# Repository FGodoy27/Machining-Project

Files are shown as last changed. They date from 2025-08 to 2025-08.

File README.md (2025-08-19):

## Ballerina Project
### Ballerina Project Description
This is a project for the machining course, where we were given the option of making a figure with a free design and measurements, taking into account only the availability of materials in the laboratory.
For this project, we needed to use all the machines we have in the laboratory (milling machine, lathe, drill, planer).
It was necessary to calculate all the cuts and processes required, calculations that will be attached to this repository.

### Ballerina Project Final Assembly
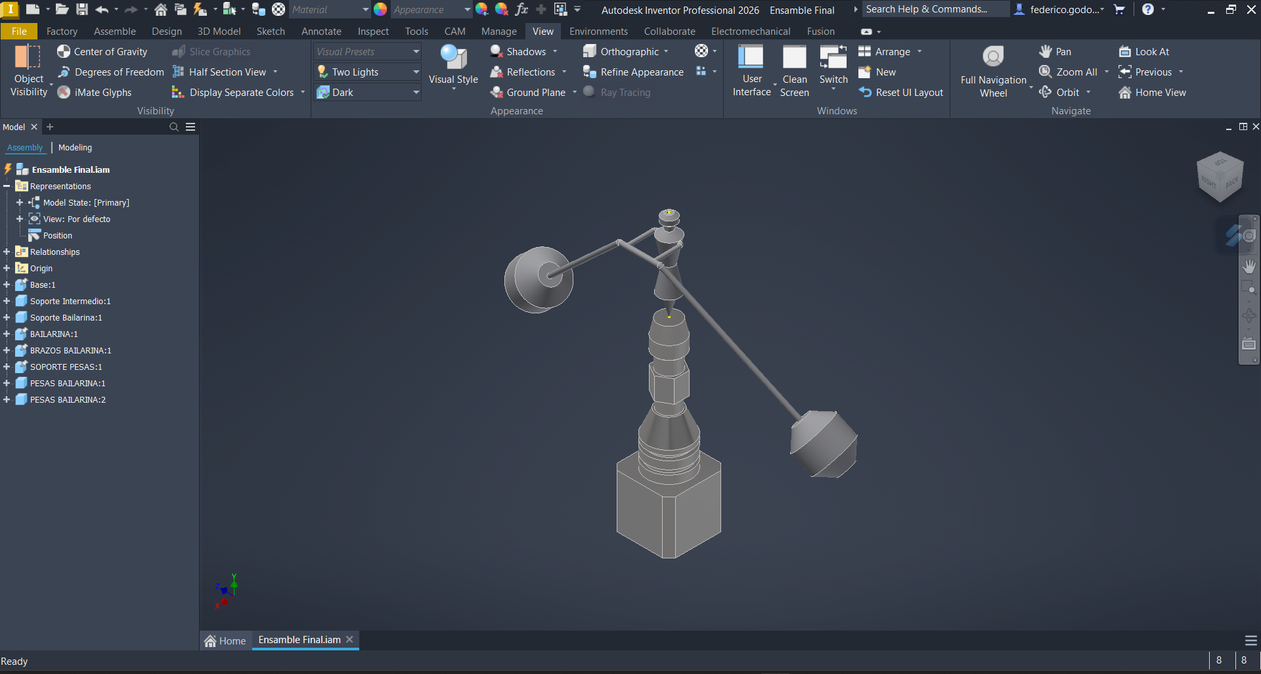
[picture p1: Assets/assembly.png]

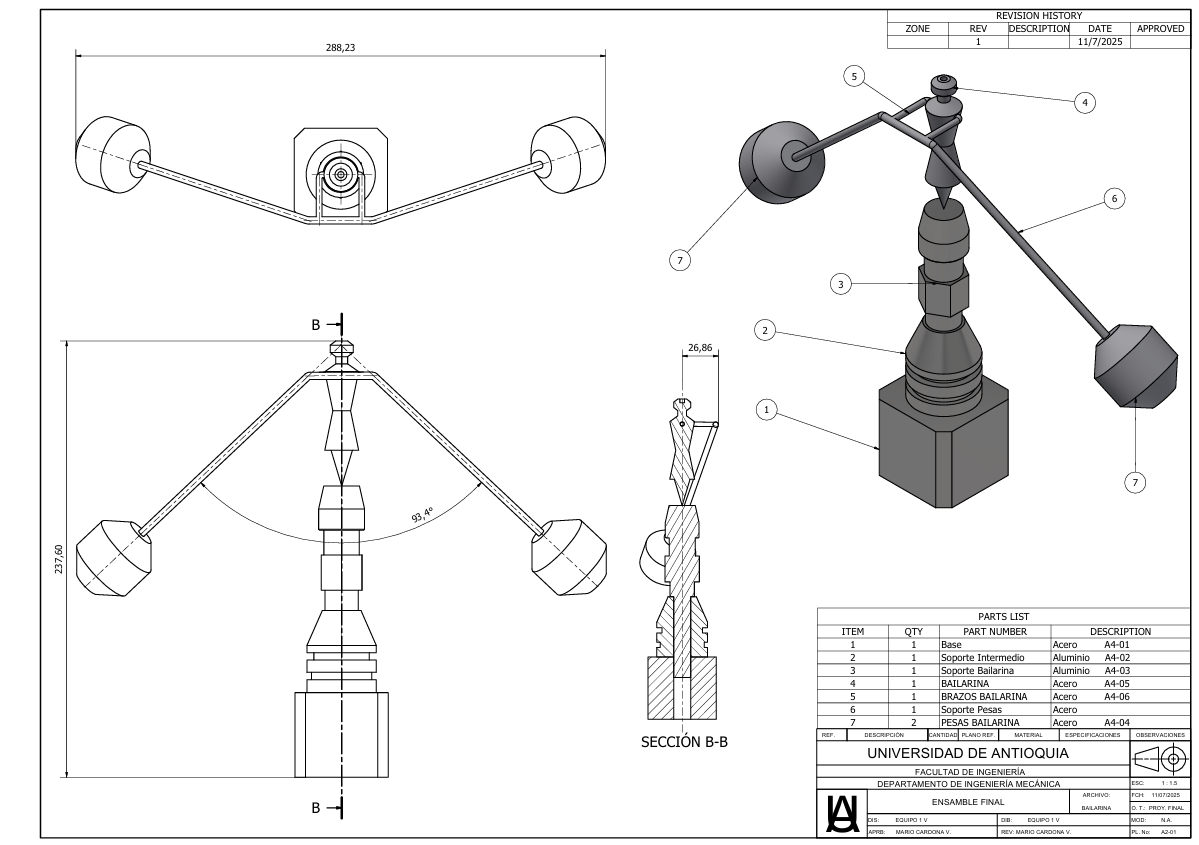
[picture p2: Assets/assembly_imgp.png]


### Final Result of the Ballerina Project
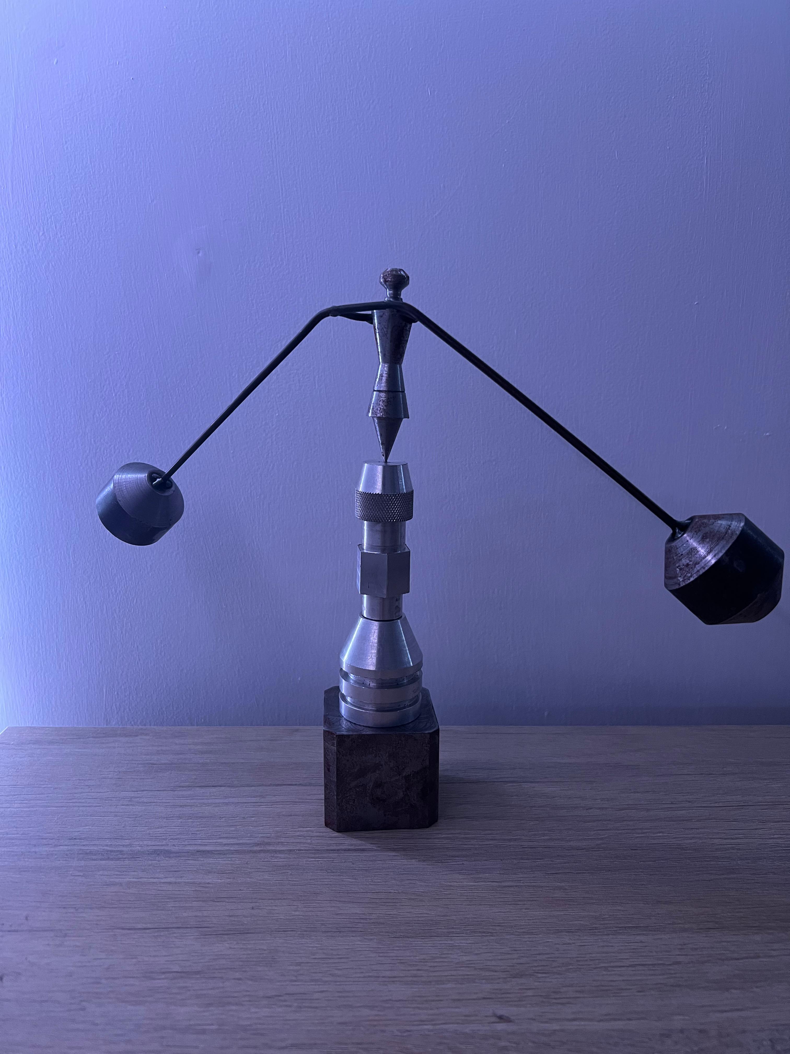
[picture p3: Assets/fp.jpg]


### Ballerina Base
The base was made of 1020 steel.
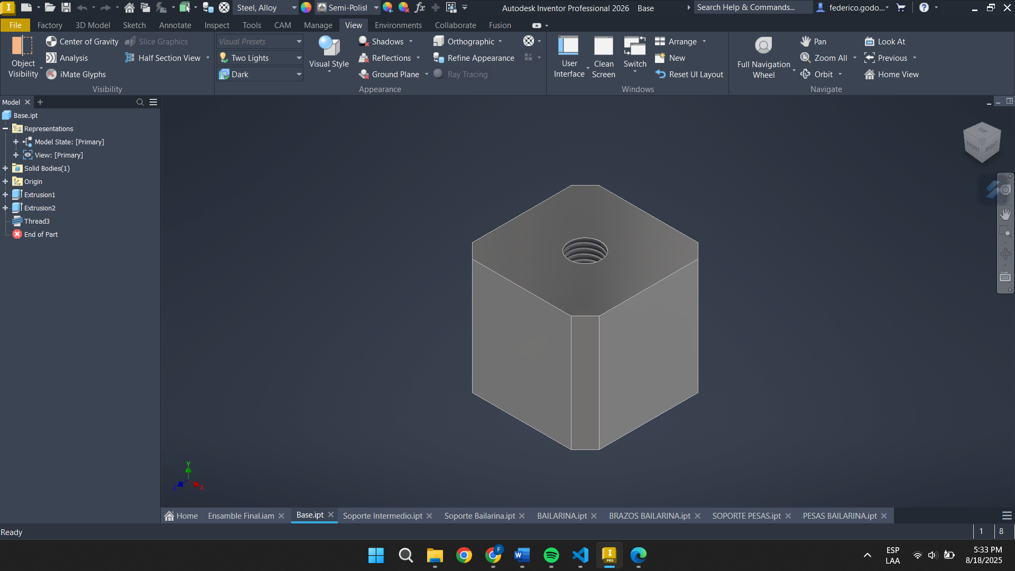
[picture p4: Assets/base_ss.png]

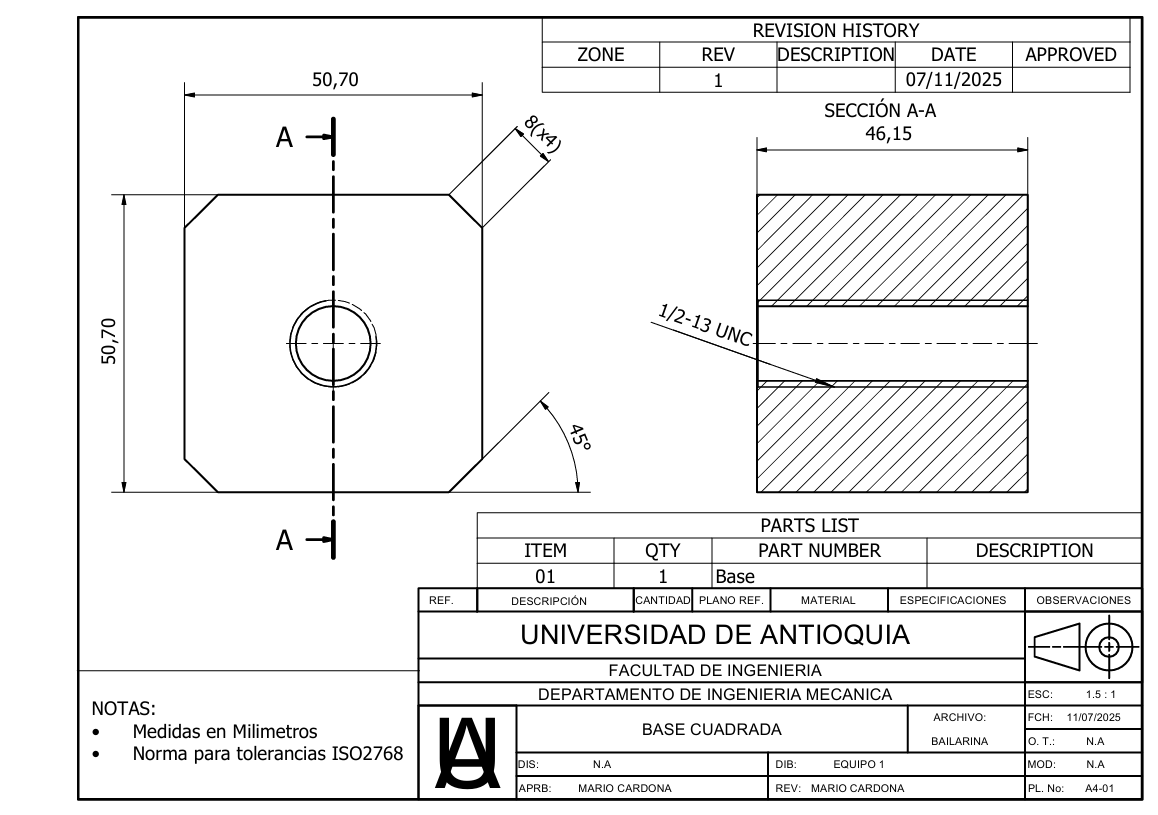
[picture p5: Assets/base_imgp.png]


### Ballerina Intermediate Support
The intermediate support is made of aluminum.
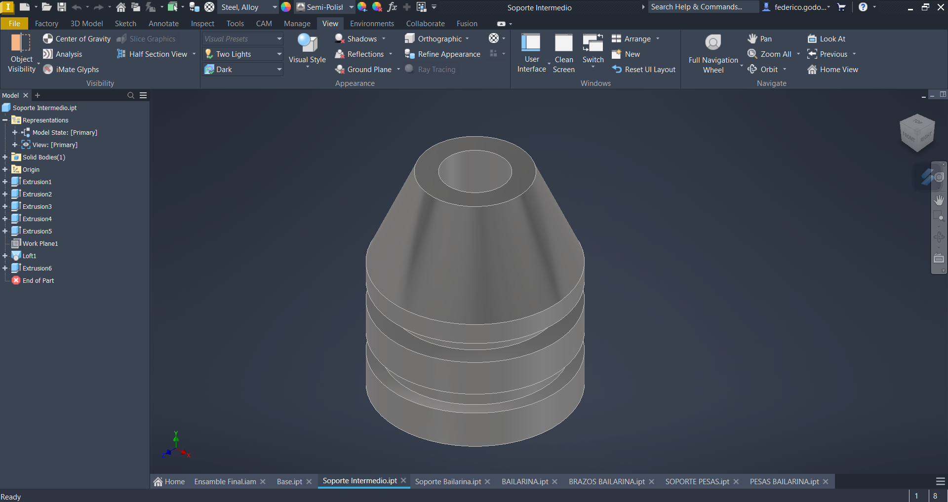
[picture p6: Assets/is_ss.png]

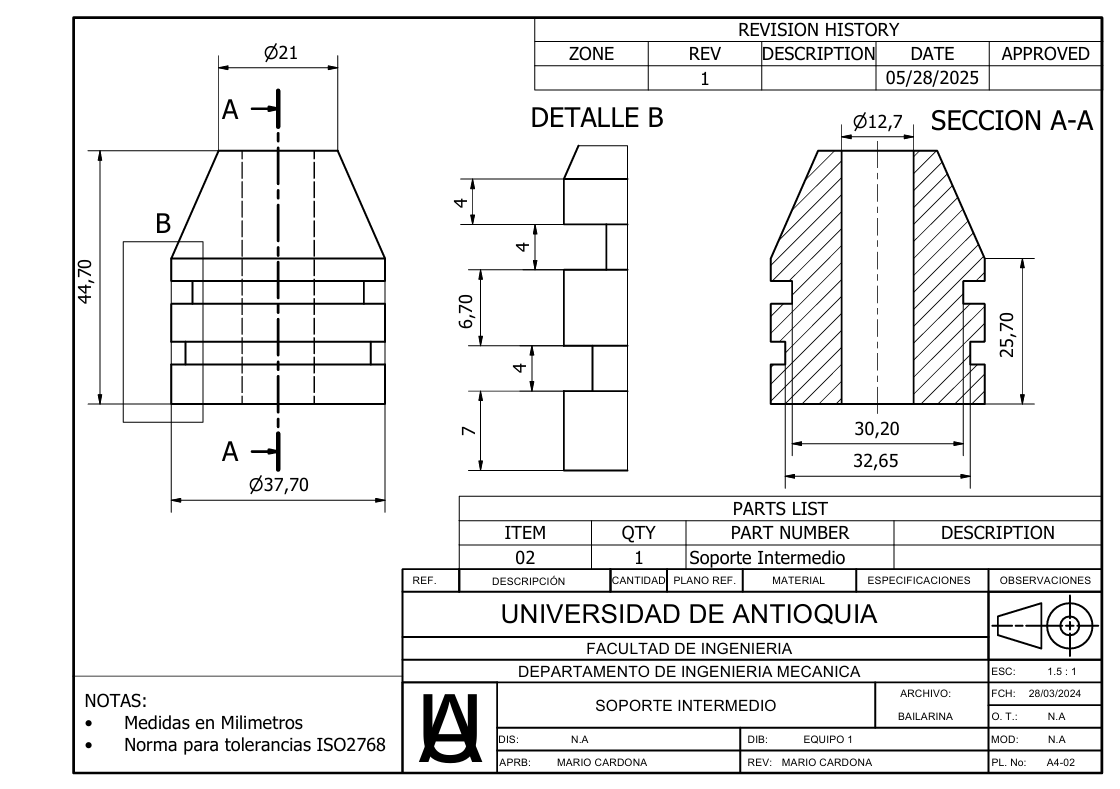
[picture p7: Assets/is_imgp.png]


### Ballerina Main Support 
The main support is made of aluminum.
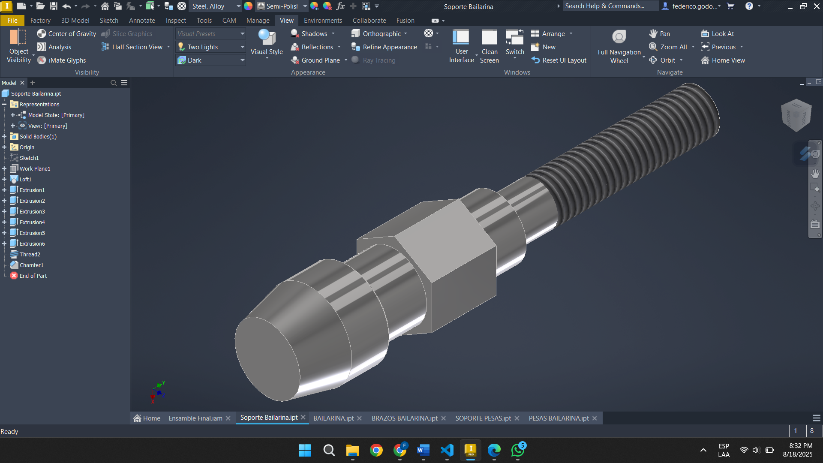
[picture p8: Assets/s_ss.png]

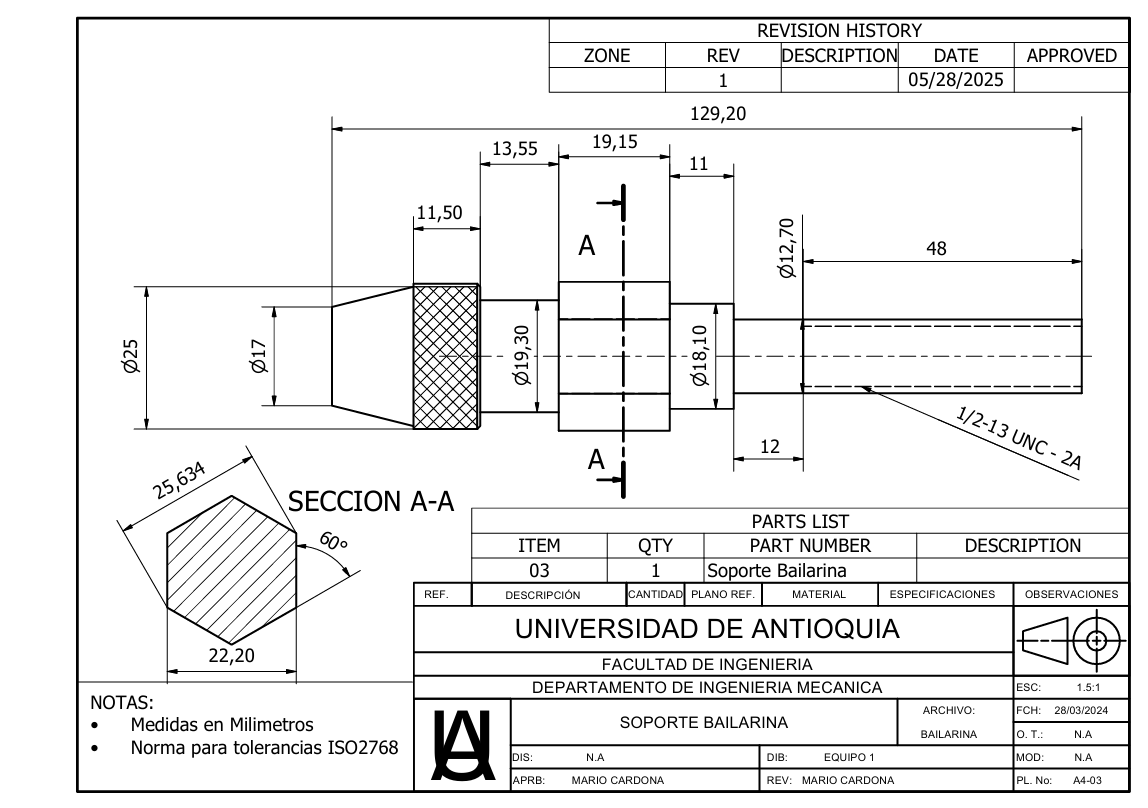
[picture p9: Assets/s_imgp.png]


### Ballerina
The ballerina was made of 1020 steel.
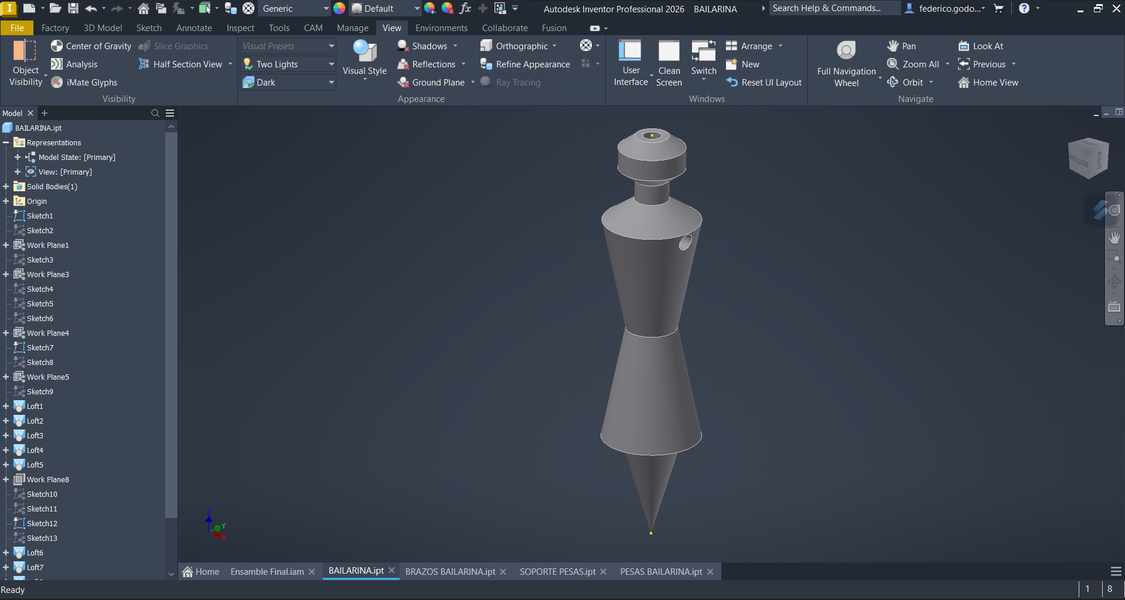
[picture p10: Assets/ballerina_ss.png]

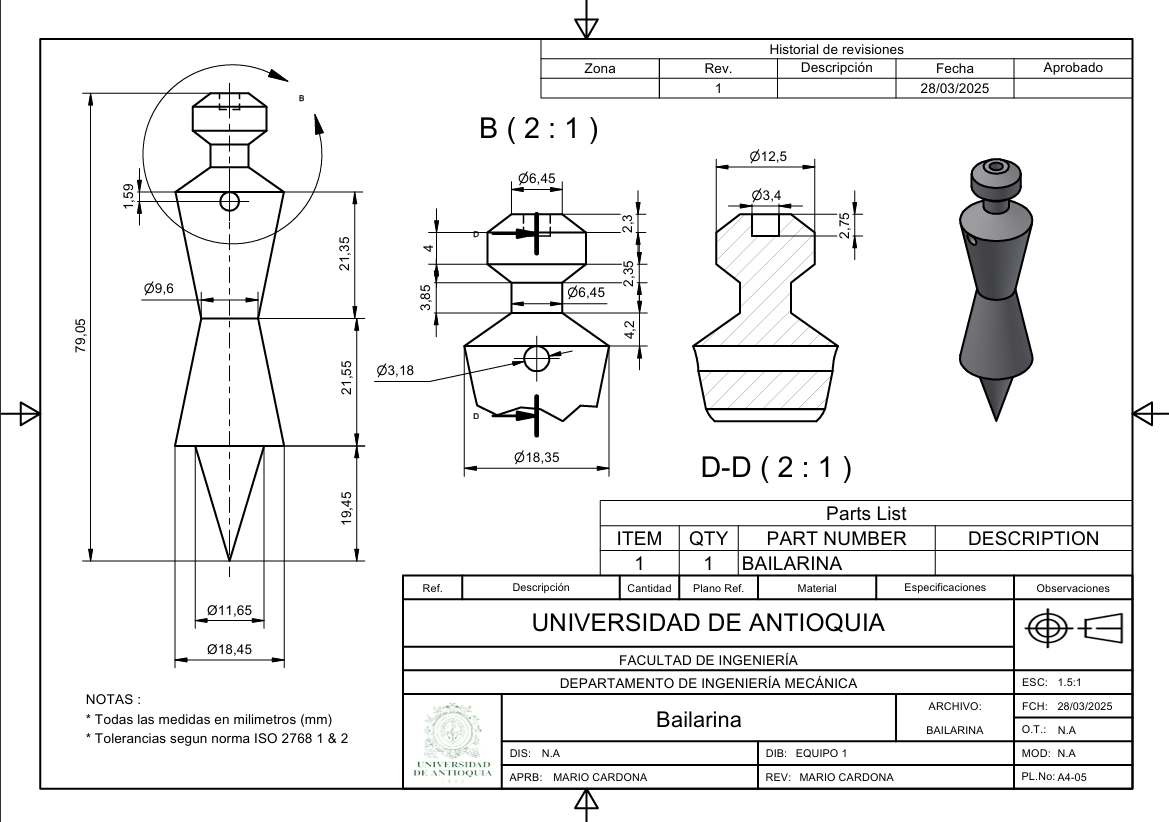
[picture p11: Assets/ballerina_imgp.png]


### Ballerina Arms
The ballerina arms were made of 1020 steel.
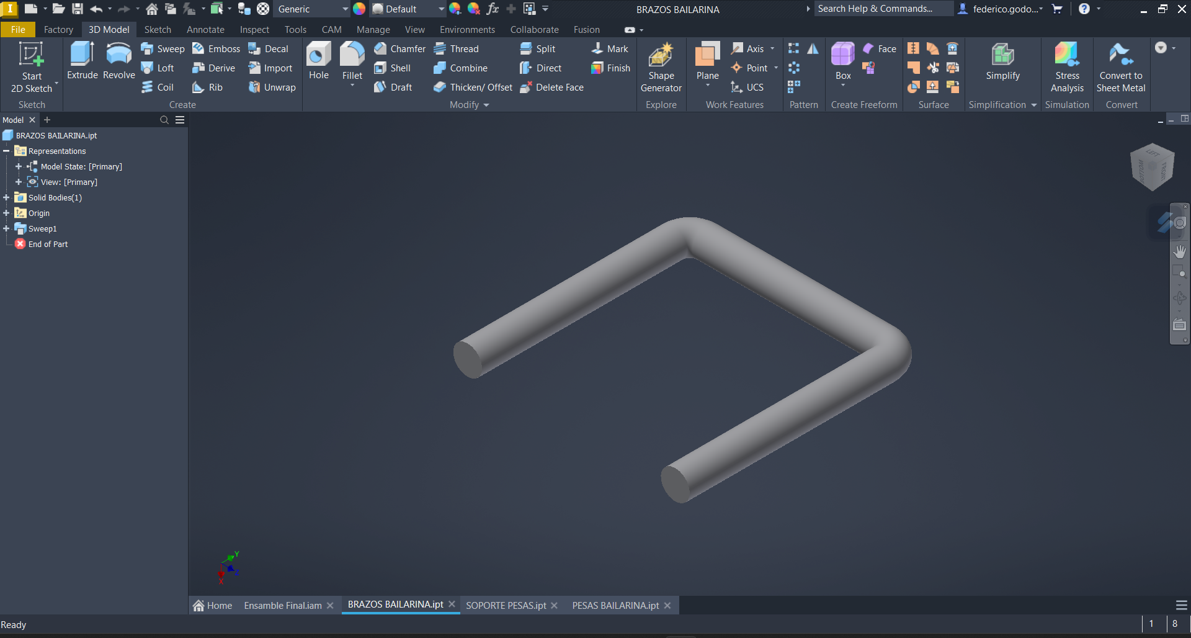
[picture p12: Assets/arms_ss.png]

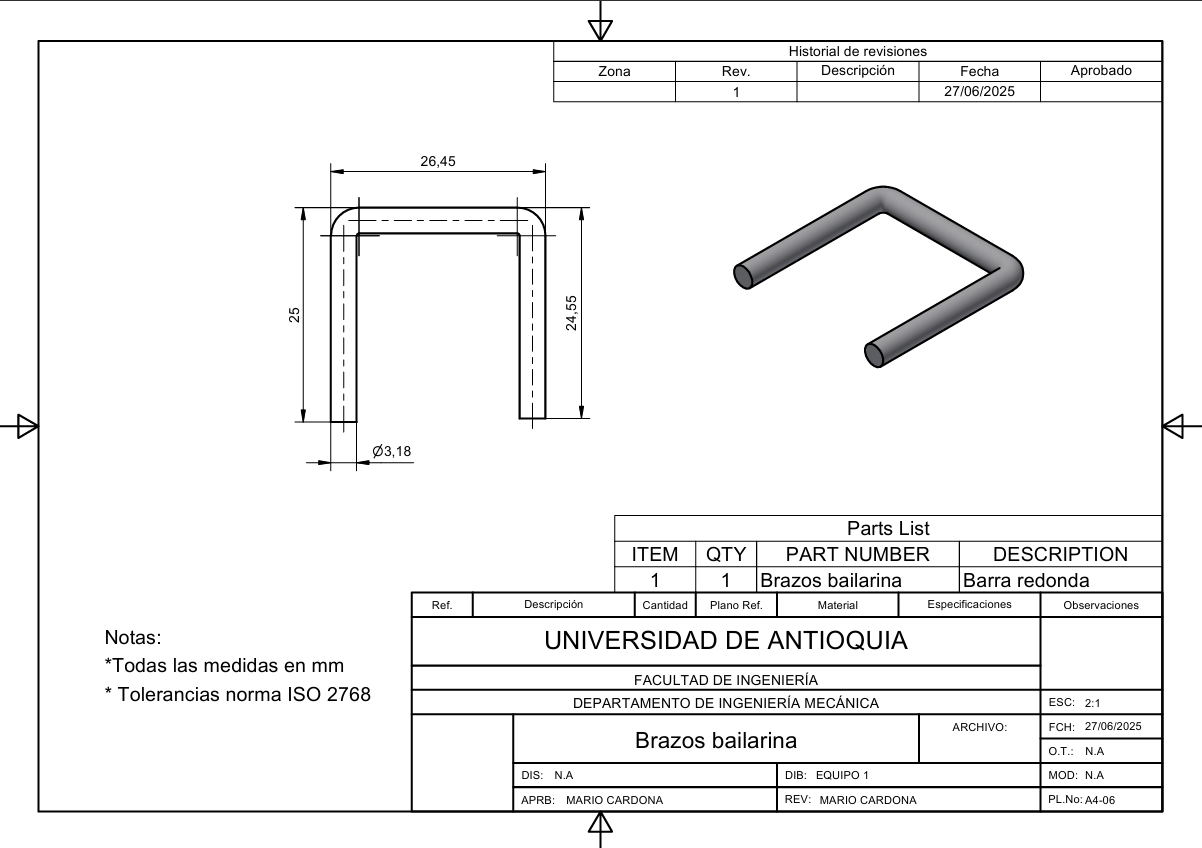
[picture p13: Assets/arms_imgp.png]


### Weight Support
The weight support of the ballerina was made of 1020 steel
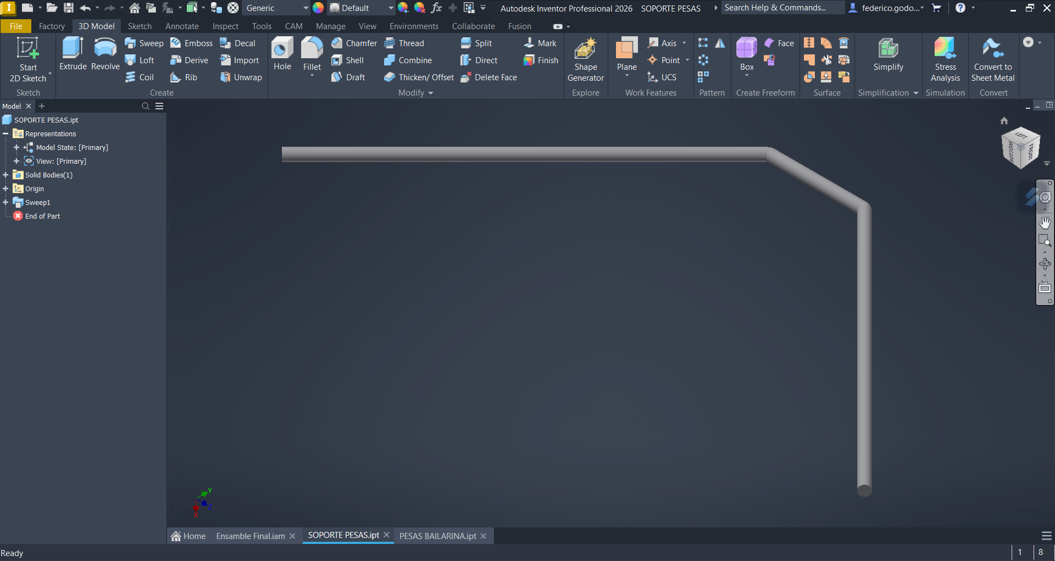
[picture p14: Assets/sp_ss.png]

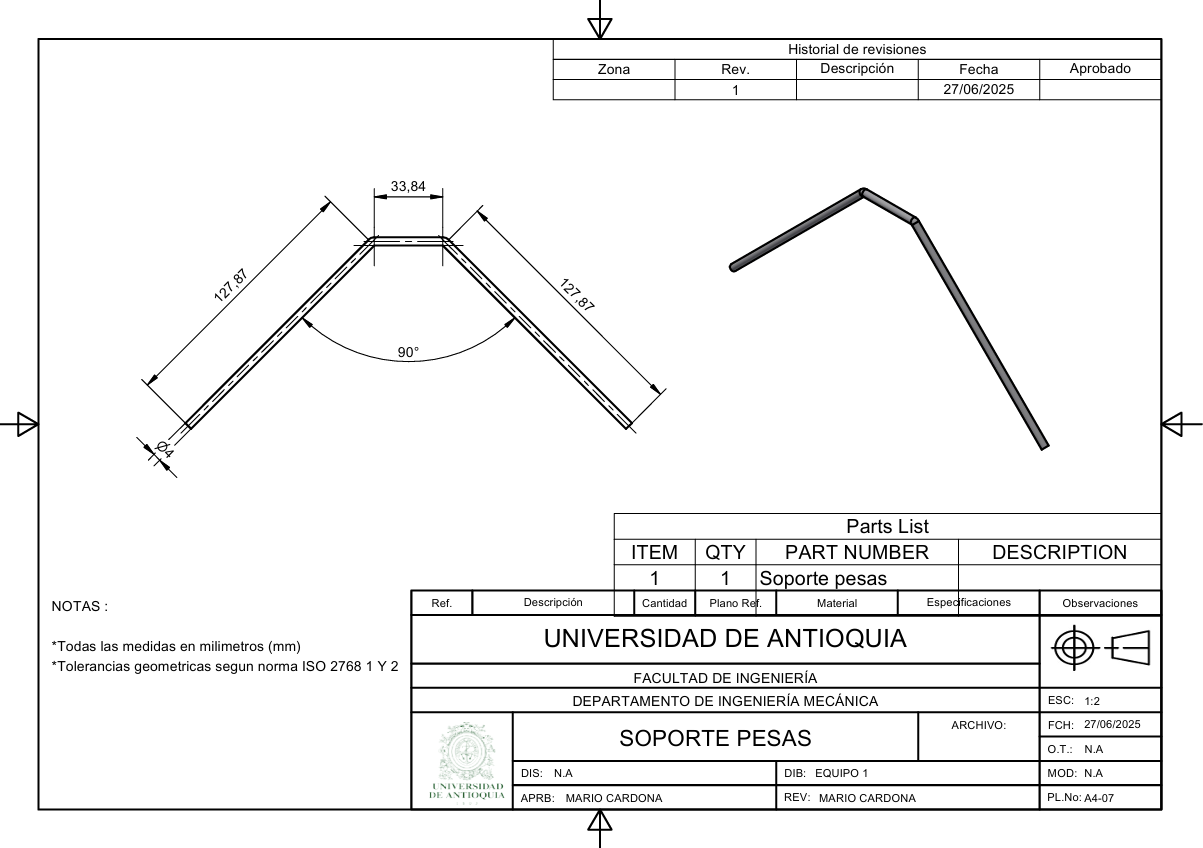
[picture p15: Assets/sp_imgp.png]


### Weights
The weights were made of 1020 steel
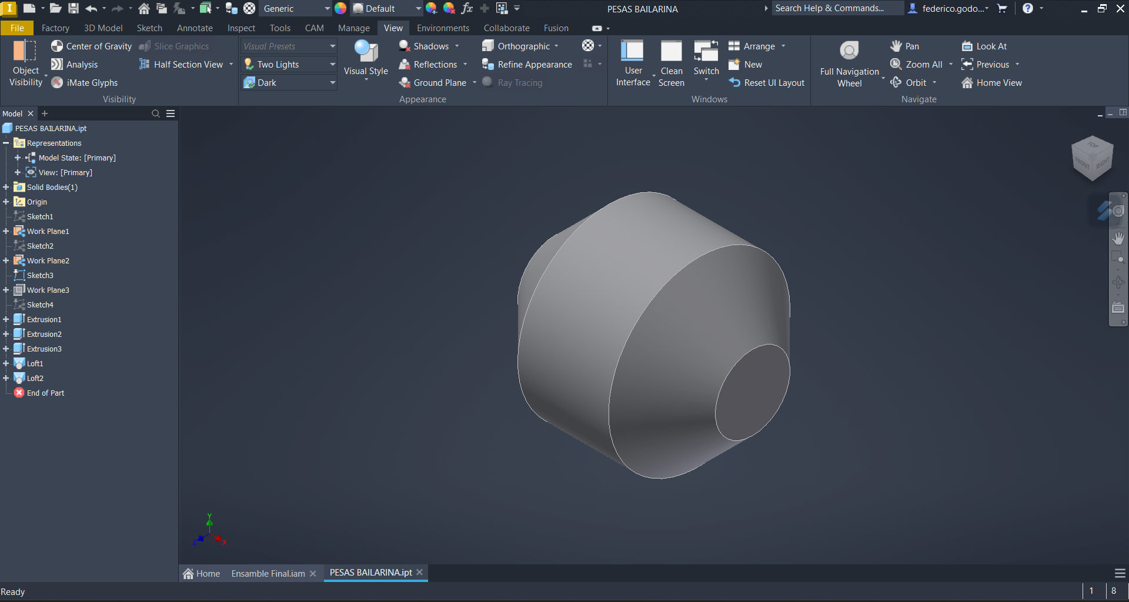
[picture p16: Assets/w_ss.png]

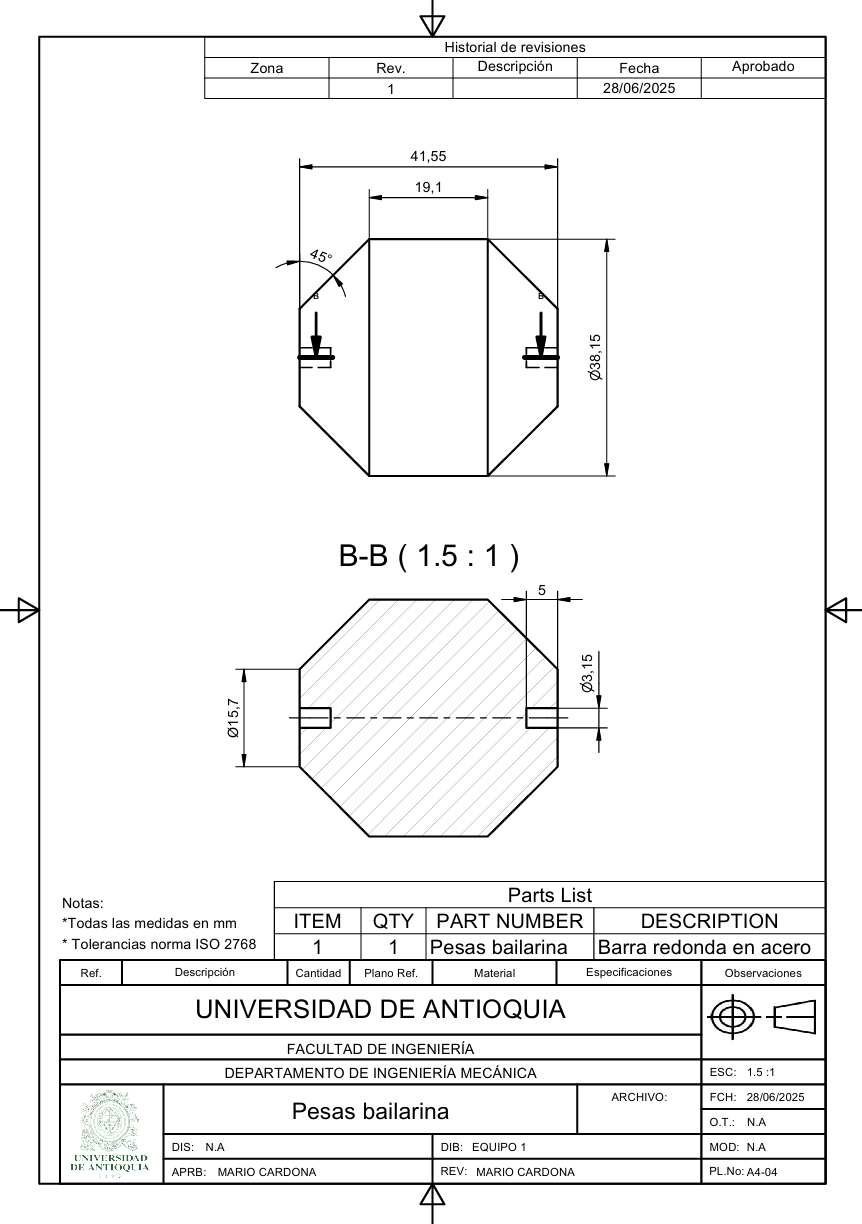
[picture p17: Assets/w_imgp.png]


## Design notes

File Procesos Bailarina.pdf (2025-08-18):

Pieza: BASE

Material: ACERO AISI 1020
Cantidad: 1
Plano: A4-01
N° | DESCRIPCIÓN | MÁQUINA | HERRAMIENTA | Vc [m/min] | RPM | f [in/rev] | Ap [mm] | # Cortes | Montaje | T. Máquina | T. Montaje
1 | Levantamiento de piezas. | N/A | Pie de rey, escuadra, galgas, Inventor. | N/A | N/A | N/A | N/A | N/A | N/A | 0:05:00 | N/A
2 | Corte de barra 50.8x50.8 mm, longitud 54.77 mm. | Sierra mecánica sin fin | Lima, pie de rey, tiza, rayador | 3.2 | 20 | N/A | N/A | 1 | Montaje al aire | 0:00:45 | 0:02:53
3 | Refrentado de ambas caras para alcanzar 50.70 mm. | Limadora | Buril HSS 1/2", refrigerante | 18.3 | — | 0.010 | 2.0 | 2 | Montaje en prensa fija | 0:08:00 | 0:25:00
4 | Corte de aristas 1 a 4. | Fresadora | Fresa de carburo, refrigerante | 60 | 750 | 0.15 | 1.5 | 4 | Montaje en prensa fija | 0:15:00 | 0:20:00
5 | Taladrado Ø10.72 mm, profundidad 42 mm. | Taladro radial | Broca 27/64", refrigerante, prensa | 30 | 900 | N/A | 42 | 1 | Montaje con prensa | 0:03:00 | 0:03:00
6 | Rosca interna 1/2-13 UNC | Manual | Juego de machuelos y bandeador | N/A | N/A | N/A | N/A | 3 | Montaje en prensa | 0:04:00 | 0:05:00
7 | Redondeos en aristas superiores | Esmeril | Gafas, limadora plana | N/A | N/A | N/A | N/A | N/A | Montaje manual | N/A | 0:05:00

Pieza: SOPORTE INTERMEDIO

Material: ALUMINIO
Cantidad: 1
Plano: A4-02
N° | DESCRIPCIÓN | MÁQUINA | HERRAMIENTA | Vc [m/min] | RPM | f [in/rev] | Ap [mm] | # Cortes | Montaje | T. Máquina | T. Montaje
1 | Levantamiento de piezas. | N/A | Pie de rey, escuadra, galgas, Inventor. | N/A | N/A | N/A | N/A | N/A | N/A | 0:05:00 | N/A
2 | Corte de barra Ø44.7 mm, longitud 46.7 mm. | Sierra mecánica sin fin | Lima, pie de rey, tiza, rayador | 3.2 | 20 | N/A | N/A | 1 | Montaje al aire | 0:00:45 | 0:01:20
3 | Refrentado de ambas caras hasta 44.7 mm. | Torno paralelo | Buril HSS 1/4”, refrigerante | 53 | 450 | Manual | 0.8 | 2 | Montaje al aire | 0:04:00 | 0:03:00
4 | Centrado cara 1 | Torno paralelo | Broca centro, portamadriles | 21 | 900 | N/A | N/A | 1 | Montaje al aire | 0:01:00 | 0:01:00
5 | Ranurado Ø21 mm a Ø17 mm, longitud 25 mm | Torno paralelo | Buril ranurado, refrigerante | 27 | 450 | Manual | 0.63 | 3 | Montaje con contrapunto | 0:05:00 | 0:03:30
6 | Taladrado pasante Ø12.7 mm | Taladro de banco | Broca 1/2”, refrigerante | 30 | 3000 | N/A | N/A | 1 | Montaje con prensa | 0:02:00 | 0:02:00

Pieza: SOPORTE BAILARINA

Material: ALUMINIO
Cantidad: 1
Plano: A4-03
N° | DESCRIPCIÓN | MÁQUINA | HERRAMIENTA | Vc [m/min] | RPM | f [in/rev] | Ap [mm] | # Cortes | Montaje | T. Máquina | T. Montaje
1 | Levantamiento de piezas y análisis de geometría. | N/A | Pie de rey, galgas, escuadra, Inventor | N/A | N/A | N/A | N/A | N/A | N/A | 0:05:00 | N/A
2 | Corte de barra Ø26 mm, longitud 135 mm. | Sierra sin fin | Tiza, rayador, lima | — | — | — | — | 1 | Montaje al aire | 0:01:00 | 0:01:30
3 | Refrentado de ambas caras hasta longitud 129.20 mm. | Torno paralelo | Buril HSS 1/4", refrigerante | 40 | 350 | 0.12 | 1.0 | 2 | Montaje en plato | 0:04:00 | 0:02:00
4 | Torneado de cono Ø17 a Ø25 mm, longitud 14 mm, 31.88° | Torno paralelo | Buril de forma, carro inclinado 15.94° | 40 | 350 | Manual | — | 1 | Montaje en plato | 0:04:00 | 0:02:00
5 | Moleteado Ø13 mm, longitud 11.50 mm (patrón cruzado). | Torno paralelo | Rueda de moleteado | — | 200 | — | — | 1 | Montaje en plato | 0:03:00 | 0:01:00
6 | Torneado zona cilíndrica Ø13.55 mm. | Torno paralelo | Buril HSS fino, refrigerante | 40 | 350 | 0.1 | 0.8 | 1 | Montaje en plato | 0:03:00 | 0:01:00
7 | Fresado de sección hexagonal con 22.2 mm entre caras. | Fresadora | Fresa de carburo plana, refrigerante | 60 | 750 | — | 1.0 | 6 | Prensa de banco | 0:10:00 | 0:03:00
8 | Torneado Ø11 mm (post hexágono). | Torno paralelo | Buril HSS fino, refrigerante | 40 | 350 | 0.1 | 0.8 | 1 | Montaje en plato | 0:03:00 | 0:01:00
9 | Torneado Ø12 mm | Torno | Buril HSS fino, | 40 | 350 | 0.1 | 0.8 | 1 | Montaje | 0:03:00 | 0:01:00

| | paralelo | refrigerante | | | | | | en plato
10 | Roscado externo (probable 1/2 -13 UNC, longitud 48 mm). | Torno paralelo | Herramienta de roscado externa, lubricante | — | 100 | — | — | 1 | Montaje en plato | 0:05:00 | 0:02:00

Pieza: BAILARINA

Material: ACERO AISI 1020
Cantidad: 1
Plano: A4-05
N° | DESCRIPCIÓN | MÁQUINA | HERRAMIENTA | Vc [m/min] | RPM | f [in/rev] | Ap [mm] | # Cortes | Montaje | T. Máquina | T. Montaje
1 | Levantamiento de piezas y análisis de geometría. | N/A | Pie de rey, galgas, Inventor | N/A | N/A | N/A | N/A | N/A | N/A | 0:05:00 | N/A
2 | Corte de barra Ø20 mm, longitud 82 mm. | Sierra sin fin | Tiza, rayador, lima | — | — | — | — | 1 | Montaje al aire | 0:01:00 | 0:01:30
3 | Refrentado de ambas caras hasta longitud final 79.05 mm. | Torno paralelo | Buril HSS, refrigerante | 40 | 350 | 0.12 | 1.0 | 2 | Montaje en plato | 0:04:00 | 0:02:00
4 | Taladrado axial Ø3.4 mm, profundidad 2.75 mm. | Torno paralelo | Broca 3.4 mm, lubricante | 30 | 1800 | — | 2.75 | 1 | Montaje en plato | 0:02:00 | 0:01:00
5 | Torneado cono Ø6.45 → Ø12.5, longitud 2.75 mm (ángulo ~62.6°) | Torno paralelo | Buril de forma, carro inclinado | 40 | 350 | Manual | — | 1 | Montaje en plato | 0:03:00 | 0:01:00
6 | Torneado cilíndrico Ø12.5 mm, longitud 3.00 mm. | Torno paralelo | Buril HSS fino | 40 | 350 | 0.10 | 0.8 | 1 | Montaje en plato | 0:02:00 | 0:01:00
7 | Torneado cono Ø12.5 → Ø6.45 mm, longitud 2.35 mm. | Torno paralelo | Buril de forma, carro inclinado | 40 | 350 | Manual | — | 1 | Montaje en plato | 0:03:00 | 0:01:00
8 | Torneado cilíndrico Ø6.45 mm, longitud 3.85 mm. | Torno paralelo | Buril HSS fino | 40 | 350 | 0.10 | 0.8 | 1 | Montaje en plato | 0:02:00 | 0:01:00

9 | Torneado cono Ø6.45 → Ø18.35 mm, longitud 4.20 mm. | Torno paralelo | Buril de forma, carro inclinado | 40 | 350 | Manual | — | 1 | Montaje en plato | 0:03:00 | 0:01:00
10 | Torneado cono Ø18.35 → Ø9.6 mm, longitud 21.35 mm | Torno paralelo | Buril de forma, carro inclinado | 40 | 350 | Manual | — | 1 | Montaje en plato | 0:04:00 | 0:01:00
11 | Torneado cono Ø9.6 → Ø18.45 mm, longitud 21.55 mm. | Torno paralelo | Buril de forma, carro inclinado | 40 | 350 | Manual | — | 1 | Montaje en plato | 0:04:00 | 0:01:00
12 | Torneado cono Ø10 → Ø0 mm, longitud 19.45 mm (punta). | Torno paralelo | Buril de forma fina, punta viva | 40 | 350 | Manual | — | 1 | Montaje en plato | 0:04:00 | 0:01:00
13 | Taladrado pasante Ø3.18 mm. | Taladro de banco | Broca 1/8", refrigerante | 30 | 3000 | — | — | 1 | Prensa de banco | 0:02:00 | 0:01:30

Pieza: BRAZOS BAILARINA

Material: ACERO AISI 1020
Cantidad: 1
Plano: A4-06
N° | DESCRIPCIÓN | HERRAMIENTA | COMPLEMENTOS | OBSERVACIONES | T. Estimado
1 | Corte y escuadrado de varilla Ø10 mm, longitud 127.87 mm | Lima plana o segueta | Tornillo de banco, escuadra | Corte y ajuste manual hasta medida final | 0:05:00
2 | Doblado a 90° | Dobladora manual | Tope a 90°, transportador | Verificar ángulo con escuadra | 0:03:00

Pieza: PESAS BAILARINA

Material: ACERO AISI 1020
Cantidad: 2
Plano: A4-04
N° | DESCRIPCIÓN | MÁQUINA | HERRAMIENTA | Vc [m/min] | RPM | f [in/rev] | Ap [mm] | # Cortes | Montaje | T. Máquina | T. Montaje
1 | Levantamiento de geometría y verificación en plano. | N/A | Pie de rey, Inventor, escuadra | — | — | — | — | — | — | 0:05:00 | —
2 | Corte de barra Ø40 mm, longitud 44 mm. | Sierra sin fin | Tiza, rayador, lima | — | — | — | — | 1 | Montaje al aire | 0:01:00 | 0:01:30
3 | Refrentado de ambas caras hasta longitud 41.55 mm. | Torno paralelo | Buril HSS, refrigerante | 40 | 320 | 0.12 | 1.0 | 2 | Montaje en plato | 0:03:00 | 0:01:30
4 | Torneado de extremos cónicos Ø40 → Ø15.7 mm, ángulo 45°. | Torno paralelo | Buril de forma, carro inclinado 22.5° | 40 | 320 | Manual | — | 2 | Montaje en plato | 0:06:00 | 0:01:30
5 | Taladrado central Ø3.15 mm, profundidad 5 mm. | Torno paralelo | Broca Ø3.15 mm, tope de profundidad, refrigerante | 30 | 1200 | — | 5.0 | 1 | Montaje en plato | 0:02:00 | 0:01:00

Pieza: SOPORTE PESAS

Material: ACERO AISI 1020
Cantidad: 1
Plano: A4-07
N° | DESCRIPCIÓN | HERRAMIENTA | COMPLEMENTOS | OBSERVACIONES | T. Estimado
1 | Corte y escuadrado de varilla Ø10 mm, longitud 289.58 mm | Lima plana o segueta | Tornillo de banco, escuadra | Corte y ajuste manual hasta medida final | 0:01:00
2 | Doblado a 120° | Dobladora manual | Tope a 120°, transportador | Verificar ángulo con transportador o plantilla | 0:00:30

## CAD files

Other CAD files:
Assembly/Ensamble Final.iam
Parts/BAILARINA.ipt
Parts/BRAZOS BAILARINA.ipt
Parts/Base.ipt
Parts/PESAS BAILARINA.ipt
Parts/SOPORTE PESAS.ipt
Parts/Soporte Bailarina.ipt
Parts/Soporte Intermedio.ipt

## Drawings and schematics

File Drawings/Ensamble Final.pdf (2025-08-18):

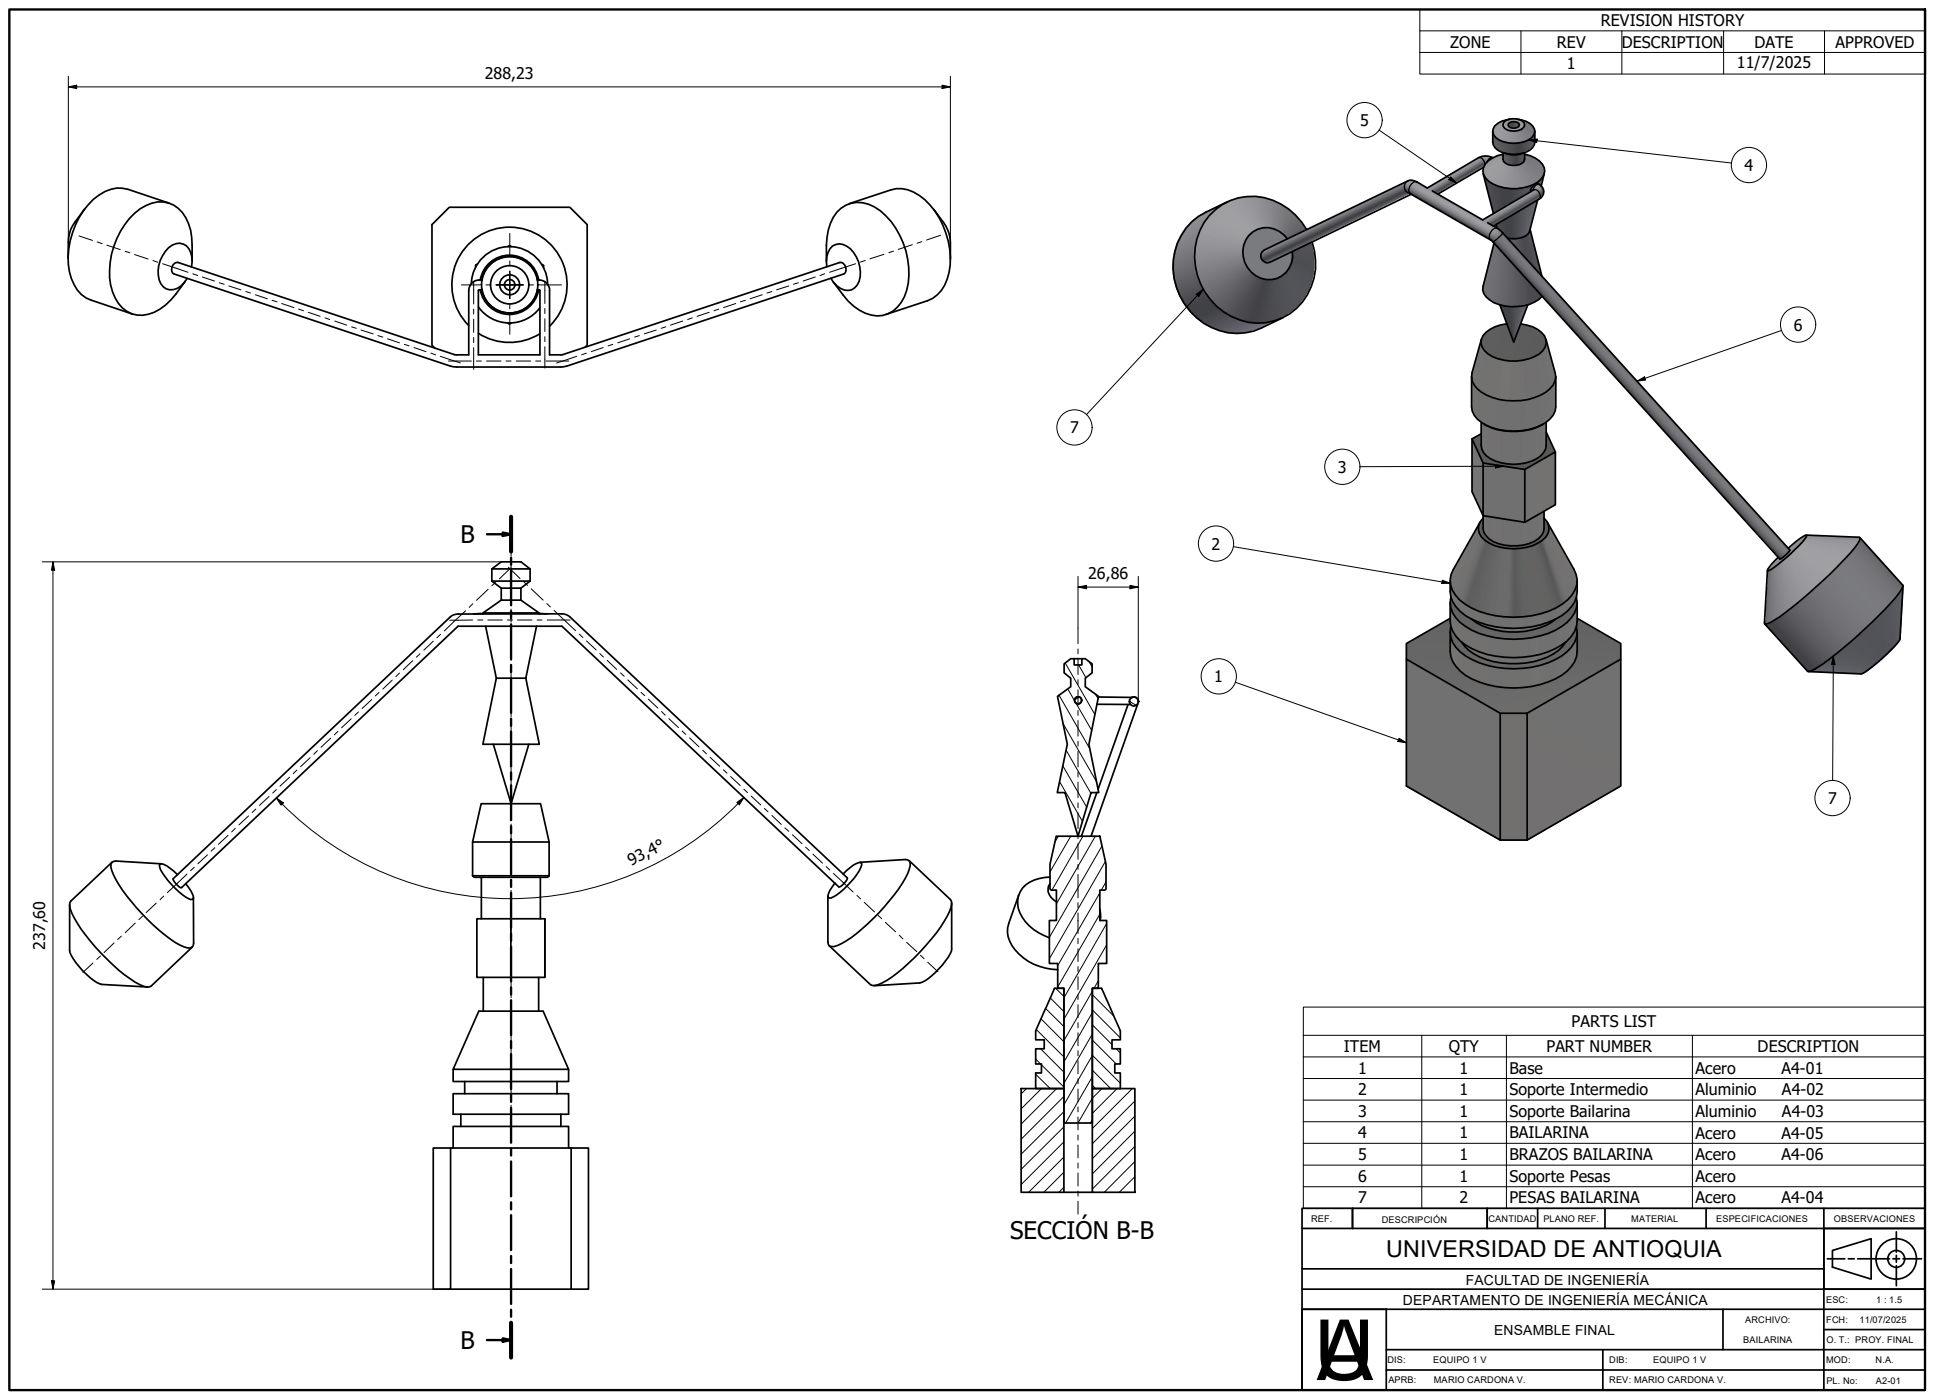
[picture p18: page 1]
SECCIÓN B-B; PARTS LIST; PROY. FINAL UA; ENSAMBLE FINAL; REVISION HISTORY

ZONE | REV | DESCRIPTION | DATE | APPROVED

ITEM | QTY | PART NUMBER | DESCRIPTION
1 | 1 | Base | Acero A4-01
2 | 1 | Soporte Intermedio | Aluminio A4-02
3 | 1 | Soporte Bailarina | Aluminio A4-03
4 | 1 | BAILARINA | Acero A4-05
5 | 1 | BRAZOS BAILARINA | Acero A4-06
6 | 1 | Soporte Pesas | Acero
7 | 2 | PESAS BAILARINA | Acero A4-04

REF. | DESCRIPCIÓN | CANTIDAD | PLANO REF. | MATERIAL | ESPECIFICACIONES | OBSERVACIONES

UNIVERSIDAD DE ANTIOQUIA

FACULTAD DE INGENIERÍA

DEPARTAMENTO DE INGENIERÍA MECÁNICA

DIS: EQUIPO 1 V | DIB: EQUIPO 1 V | MOD:

APRB: MARIO CARDONA V. | REV: MARIO CARDONA V. | PL. No: A2-01

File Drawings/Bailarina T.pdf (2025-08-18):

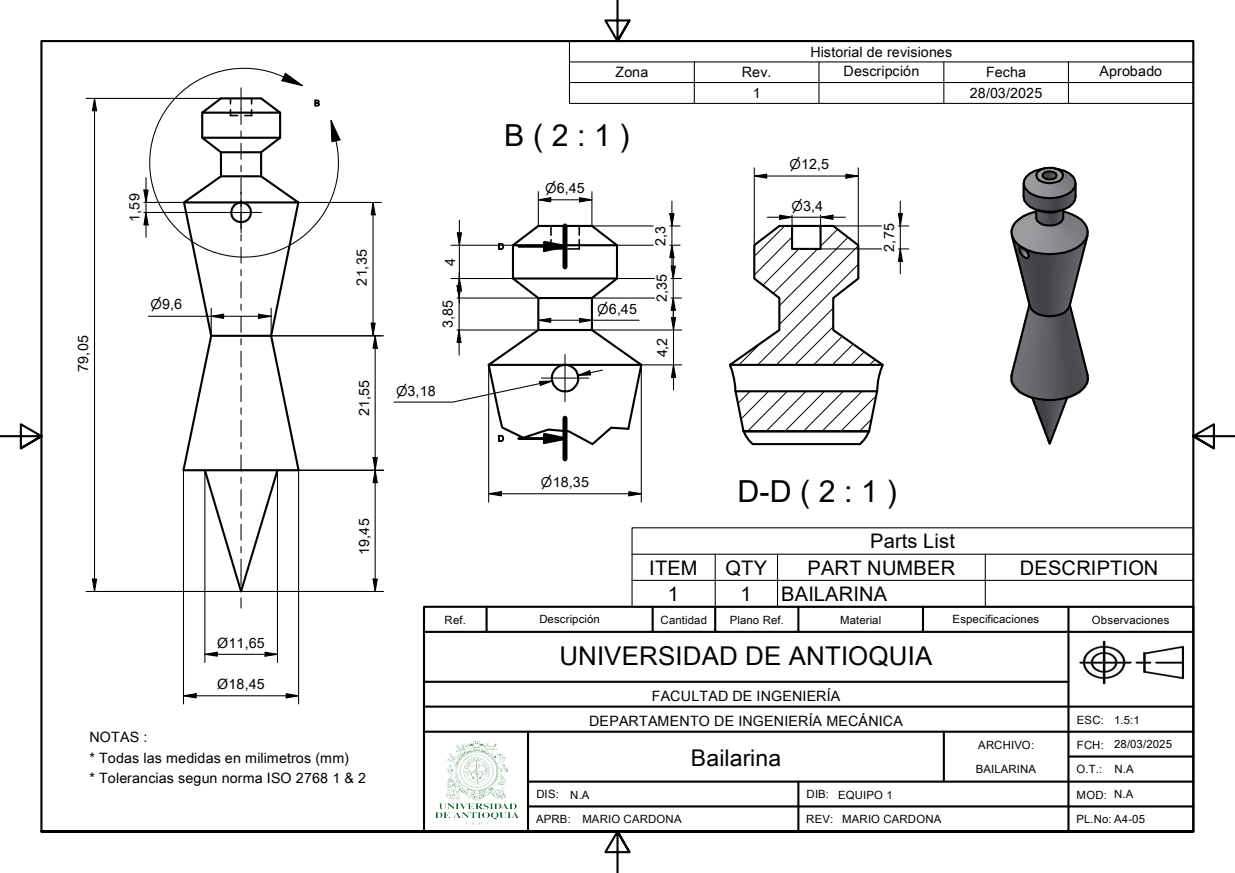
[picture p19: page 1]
Parts List

Historial de revisiones

Zona | Rev. | Descripción | Fecha | Aprobado

ITEM | QTY | PART NUMBER | DESCRIPTION
1 | 1 | BAILARINA

Ref. | Descripción | Cantidad | Plano Ref. | Material | Especificaciones | Observaciones

UNIVERSIDAD DE ANTIOQUIA

FACULTAD DE INGENIERÍA

DEPARTAMENTO DE INGENIERÍA MECÁNICA | ESC: 1.5:1

NOTAS :
* Todas las medidas en milimetros (mm)
* Tolerancias segun norma ISO 2768 1 & 2

Bailarina | ARCHIVO: BAILARINA | FCH: 28/03/2025

DIS: N.A | DIB: EQUIPO 1 | N.A MOD:

APRB: MARIO CARDONA | REV: MARIO CARDONA | PL.No: A4-05

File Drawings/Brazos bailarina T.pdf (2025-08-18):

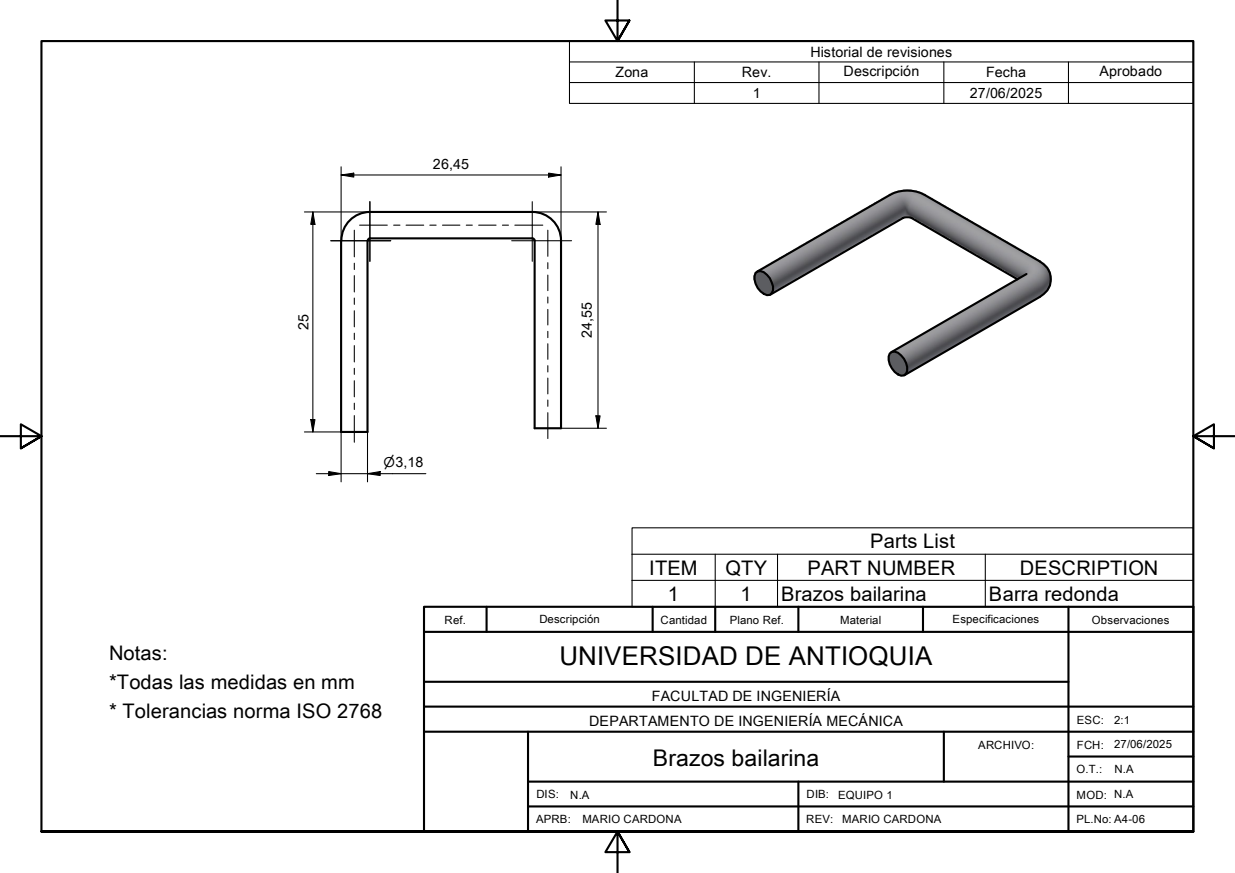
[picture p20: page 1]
Parts List

26,45 | Historial de revisiones

Zona | Rev. | Descripción | Fecha | Aprobado

ITEM | QTY | PART NUMBER | DESCRIPTION
1 | 1 | Brazos bailarina | Barra redonda

Ref. | Descripción | Cantidad | Plano Ref. | Material | Especificaciones | Observaciones

Notas:
*Todas las medidas en mm
* Tolerancias norma ISO 2768

UNIVERSIDAD DE ANTIOQUIA

FACULTAD DE INGENIERÍA

DEPARTAMENTO DE INGENIERÍA MECÁNICA | ESC: 2:1

Brazos bailarina | ARCHIVO: | FCH: 27/06/2025

DIS: N.A | DIB: EQUIPO 1 | N.A MOD:

APRB: MARIO CARDONA | REV: MARIO CARDONA | PL.No: A4-06

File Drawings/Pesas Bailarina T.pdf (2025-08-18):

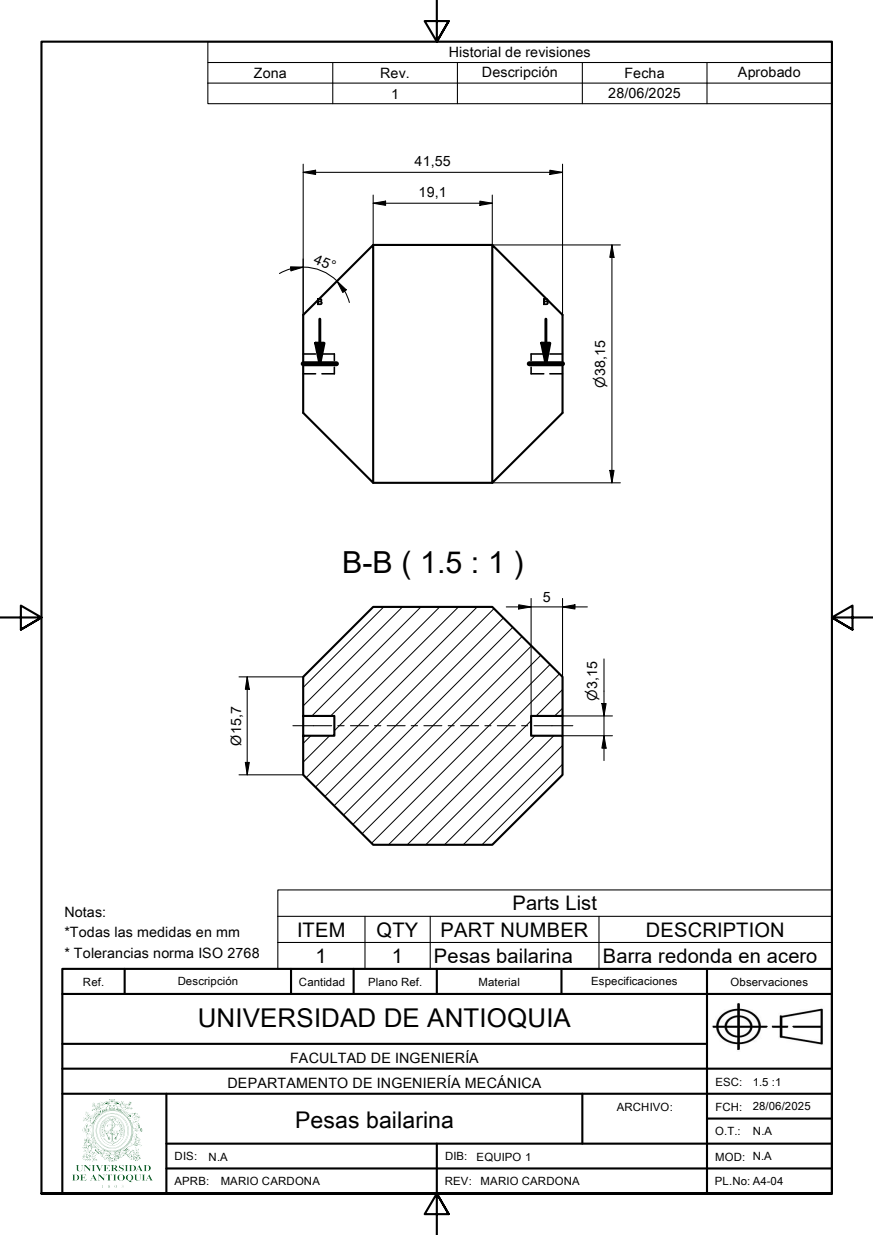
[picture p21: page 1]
Parts List

Historial de revisiones

Zona | Rev. | Descripción | Fecha | Aprobado

Notas:
*Todas las medidas en mm
* Tolerancias norma ISO 2768

ITEM | QTY | PART NUMBER | DESCRIPTION
1 | 1 | Pesas bailarina | Barra redonda en acero

Ref. | Descripción | Cantidad | Plano Ref. | Material | Especificaciones | Observaciones

UNIVERSIDAD DE ANTIOQUIA

FACULTAD DE INGENIERÍA

DEPARTAMENTO DE INGENIERÍA MECÁNICA | ESC: 1.5 :1

Pesas bailarina | ARCHIVO: | 28/06/2025 FCH:

DIS: N.A | DIB: EQUIPO 1 | MOD: N.A

APRB: MARIO CARDONA | REV: MARIO CARDONA | PL.No: A4-04

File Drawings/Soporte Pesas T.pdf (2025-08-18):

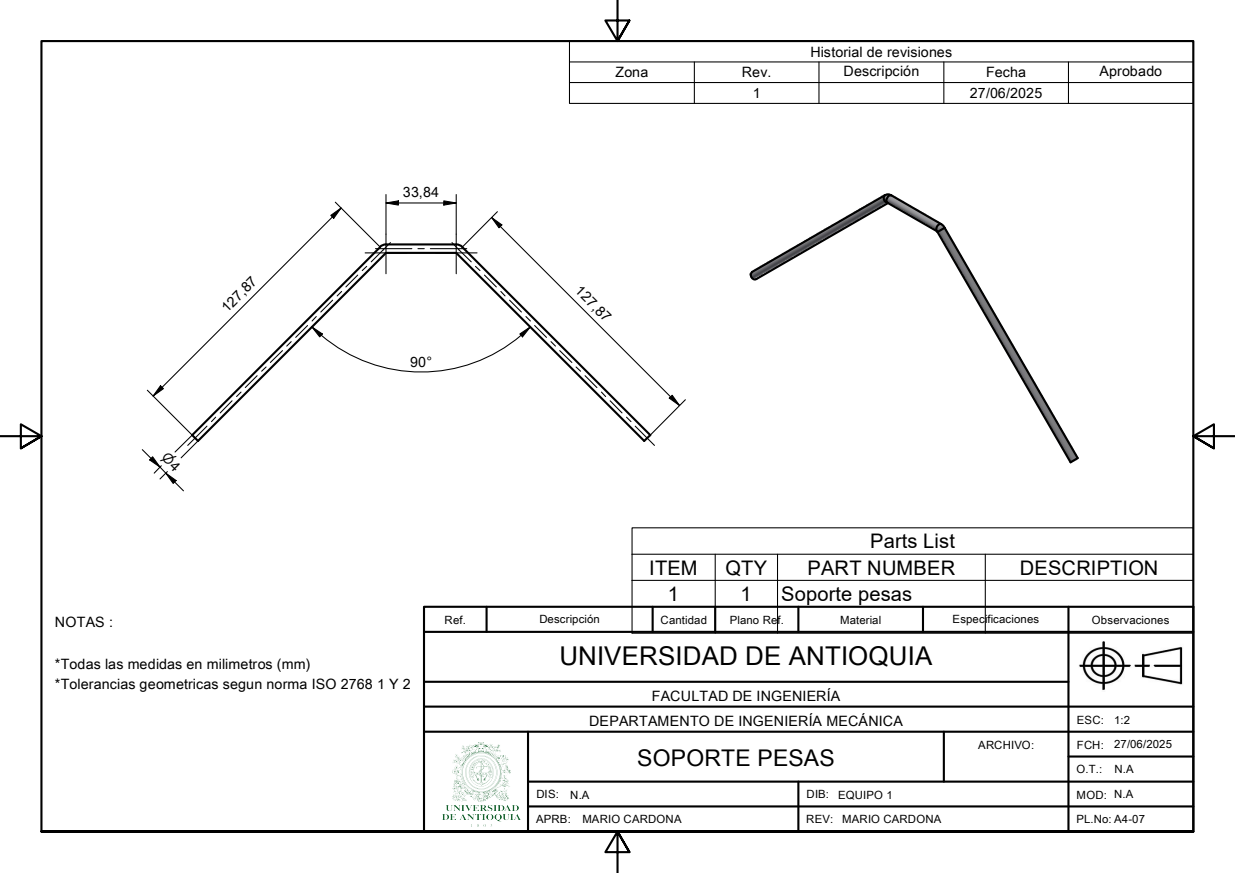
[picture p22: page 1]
Parts List; NOTAS :

33,84 | Historial de revisiones

Zona | Rev. | Descripción | Fecha | Aprobado

ITEM | QTY | PART NUMBER | DESCRIPTION
1 | 1 | Soporte pesas

Ref. | Descripción | | Cantidad | Plano Ref. | Material | Especificaciones | Observaciones

UNIVERSIDAD DE ANTIOQUIA

*Todas las medidas en milimetros (mm)
*Tolerancias geometricas segun norma ISO 2768 1 Y 2

FACULTAD DE INGENIERÍA

DEPARTAMENTO DE INGENIERÍA MECÁNICA | ESC: 1:2

SOPORTE PESAS | ARCHIVO: | FCH: 27/06/2025

DIS: N.A | DIB: EQUIPO 1 | N.A MOD:

APRB: MARIO CARDONA | REV: MARIO CARDONA | PL.No: A4-07

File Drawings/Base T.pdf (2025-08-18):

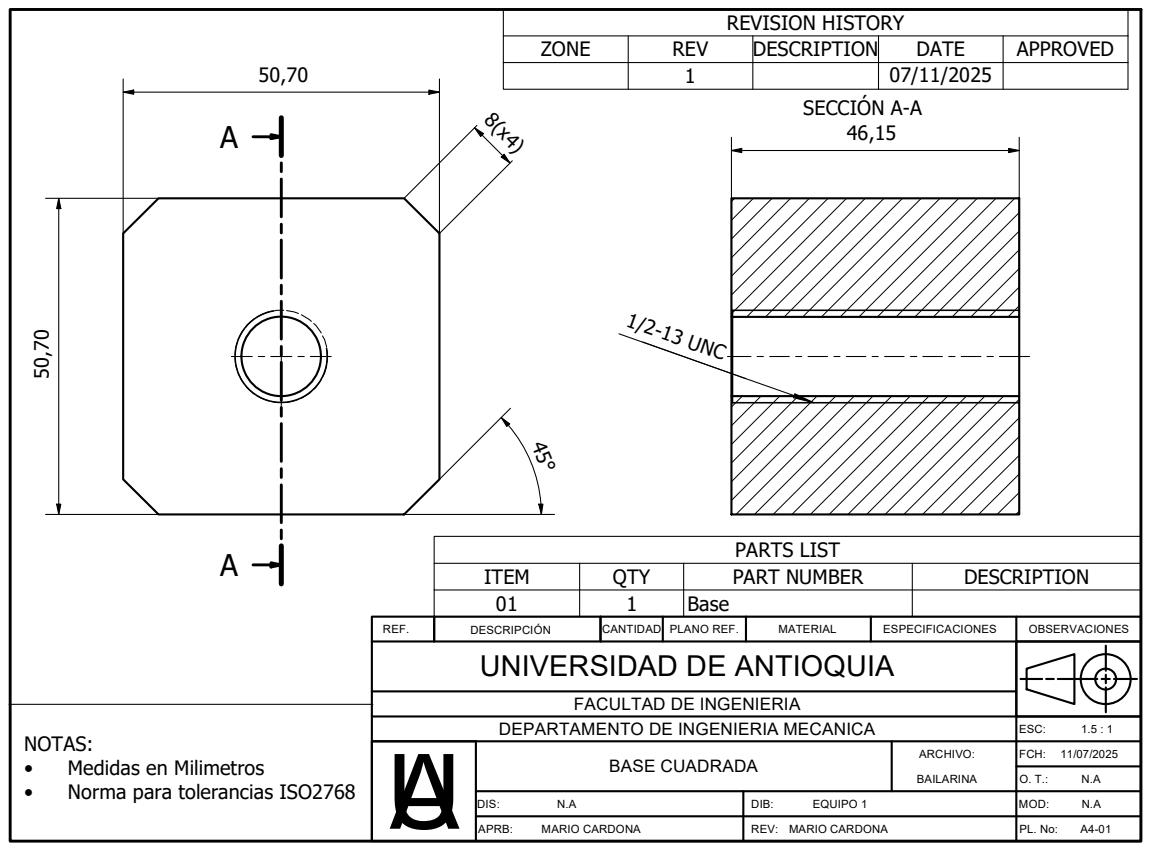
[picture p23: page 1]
PARTS LIST; BASE CUADRADA; 1/2-13 UNC; SECCIÓN A-A; REVISION HISTORY

ZONE | REV | DESCRIPTION | DATE | APPROVED

ITEM | QTY | PART NUMBER | DESCRIPTION
01 | 1 | Base

REF. | DESCRIPCIÓN | CANTIDAD | PLANO REF. | MATERIAL | ESPECIFICACIONES | OBSERVACIONES

UNIVERSIDAD DE ANTIOQUIA

FACULTAD DE INGENIERIA

DEPARTAMENTO DE INGENIERIA MECANICA

NOTAS:
• Medidas en Milimetros
• Norma para tolerancias ISO2768

DIS: N.A | DIB: EQUIPO 1 | MOD:

APRB: MARIO CARDONA | REV: MARIO CARDONA | PL. No: A4-01

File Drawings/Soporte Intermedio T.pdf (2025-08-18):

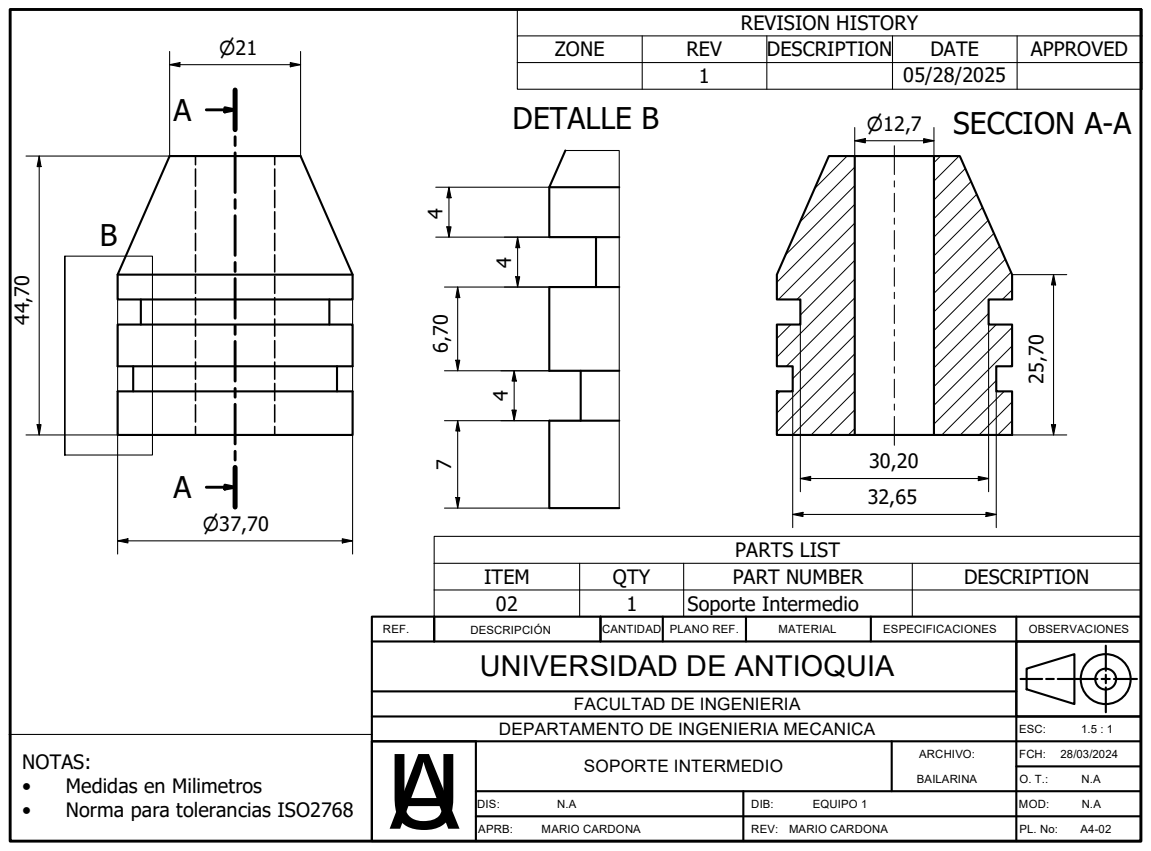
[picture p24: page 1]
DETALLE B; SECCION A-A; PARTS LIST; SOPORTE INTERMEDIO; REVISION HISTORY

ZONE | REV | DESCRIPTION | DATE | APPROVED

ITEM | QTY | PART NUMBER | DESCRIPTION
02 | 1 | Soporte Intermedio

REF. | DESCRIPCIÓN | CANTIDAD | PLANO REF. | MATERIAL | ESPECIFICACIONES | OBSERVACIONES

UNIVERSIDAD DE ANTIOQUIA

FACULTAD DE INGENIERIA

DEPARTAMENTO DE INGENIERIA MECANICA

NOTAS:
• Medidas en Milimetros
• Norma para tolerancias ISO2768

DIS: N.A | DIB: EQUIPO 1 | MOD:

APRB: MARIO CARDONA | REV: MARIO CARDONA | PL. No: A4-02

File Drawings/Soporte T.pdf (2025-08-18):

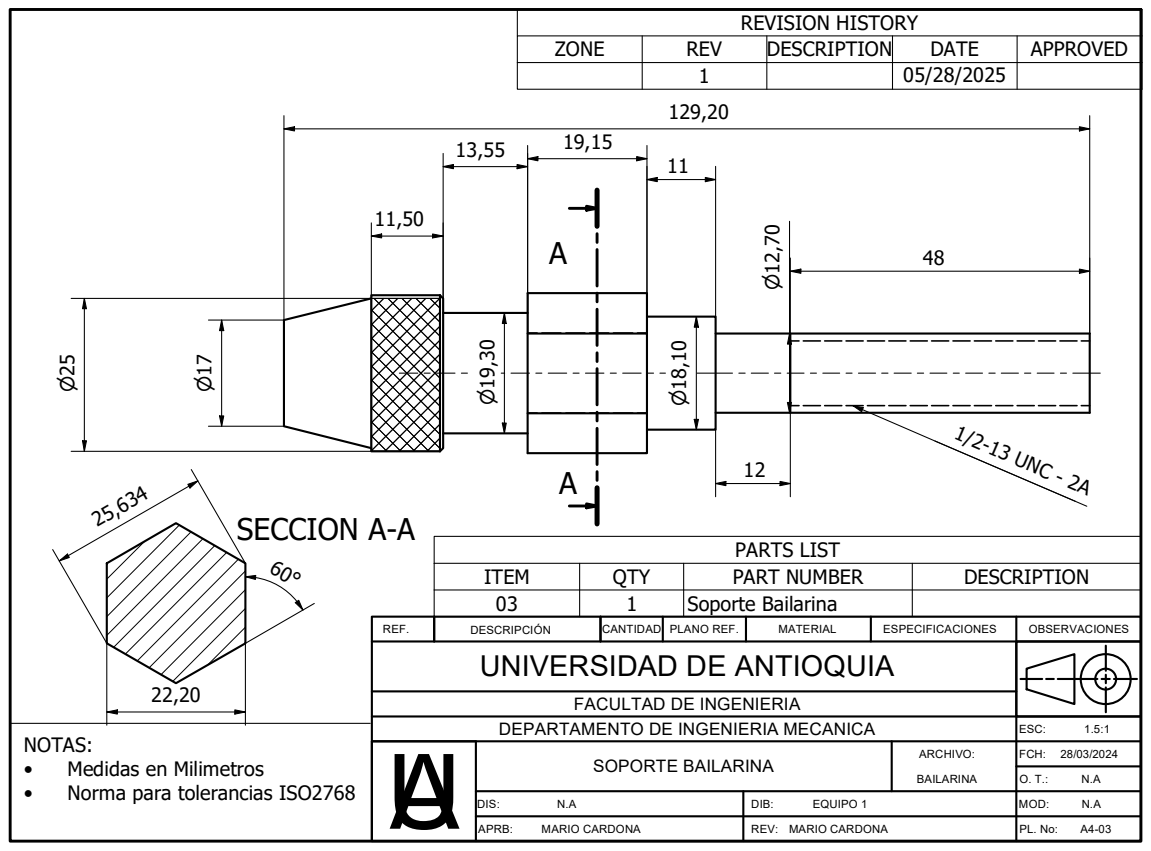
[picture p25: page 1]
SECCION A-A; PARTS LIST; SOPORTE BAILARINA; 1/2-13 UNC - 2A; REVISION HISTORY

ZONE | REV | DESCRIPTION | DATE | APPROVED

ITEM | QTY | PART NUMBER | DESCRIPTION
03 | 1 | Soporte Bailarina

REF. | DESCRIPCIÓN | CANTIDAD | PLANO REF. | MATERIAL | ESPECIFICACIONES | OBSERVACIONES

UNIVERSIDAD DE ANTIOQUIA

FACULTAD DE INGENIERIA

DEPARTAMENTO DE INGENIERIA MECANICA

NOTAS:
• Medidas en Milimetros
• Norma para tolerancias ISO2768

DIS: N.A | DIB: EQUIPO 1 | MOD:

APRB: MARIO CARDONA | REV: MARIO CARDONA | PL. No: A4-03
